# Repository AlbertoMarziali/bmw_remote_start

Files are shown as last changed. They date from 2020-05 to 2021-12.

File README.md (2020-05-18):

# BMW F30 REMOTE START
BMW F30 Remote start project, made with Arduino

# Features
This project allows to do this things:
- If the engine is off, remote start the car with a triple click on the lock button of the OEM keyfob.
- After 15 minutes from remote start, if no one started driving, automatically shut off the car
- If the engine is on, remote stop the car with a triple click on the lock button of the OEM keyfob.
- You have to unlock the car before driving it (why wouldn't you) or it will perform an emergency anti-thief stop

# How it works
The Arduino, thanks to the MCP2515 board, constantly listen to the BMW K-CAN2 bus, looking for a triple lock button click. If found, it starts a 18 seconds long operation, during which it does those steps:
1. Turns on the in-car keyfob
2. Unlocks the car
3. Locks the car 
4. Virtually presses the start button, turning on the ignition
5. Waits some seconds, to let the engine be ready to start.
6. Virtually presses the brake and the start button, turning on the engine
7. Turns off the in-car key.

# Security issues
**What happens if a thief enter the car (by smashing the window) and tries to steal it?**

If someone tries to engage a gear with the car remote started, without unlocking it with a keyfob first, the car automatically shuts off.

**The spare key is always in the car. Wouldn't this be enough to allow a thief to turn on the engine?**

Yes, but actually no. The Arduino turns on the keyfob only when it needs it to remote start. Normally the key isn't powered so the car doesn't see it and can't be turned on!

**Why do the Arduino open and close the car before starting the engine?**

The lock and unlock thing is needed to be able to turn on the ignition. This is because of the BMW security protocol, which disables the possibility of turning on the car if the car wasn't opened before. This is not a security issues though, because this process happens in 2 seconds and the car remains open for just 1 second.

# Required things
Here's a list of things you need for this project:
- Arduino Nano
- LM2596S voltage regulator board, with the output regulated to 5V
- MCP2515 Canbus board (Niren)
- 6x Relay Board with 5V relays
- 2x 560Ω (to replicate the start button internal 560Ω resistor) 
- 1x 1100Ω (to replicate the 12mA current outputted by the hall sensor inside the brake light switch)
- The spare keyfob

You can get those resistance values by putting more resistors in series and sum the resistance value.
For example:
- to get a 550Ω resistance, you can put 220Ω and 330Ω resistors in series! 
- to get a 1100Ω resistance, you can put 1kΩ and 100Ω resistors in series!

# Wiring
You have to do the wiring for:
- KCan2 bus
- 12V and GND
- Brake light switch
- Start button switches
- Keyfob battery
- Keyfob lock switch
- Keyfob unlock switch

## Car Wiring

**KCAN2**

Attention: the OBD2 port doesn't have KCAN2. You can't use it. You have to take KCAN2 from the FEM
- KCAN2_H: FEM A173\*8B, pin 50
- KCAN2_L: FEM A173\*8B, pin 49

**12V and GND**

Attention: you can't use the 12V plug as power source, you need an always-powered 12V source. You can find it at the FEM.
- 12V: FEM A173\*3B, pin 33
- GND: FEM A173\*3B, pin 6

**Brake Light Switch and Start-Stop Button**

Here you can see how to wire break light switch and start/stop button:
- The start-stop button wiring is right behind the switch button, just pull it out.
- The break light switch wiring is above the brake pedal.

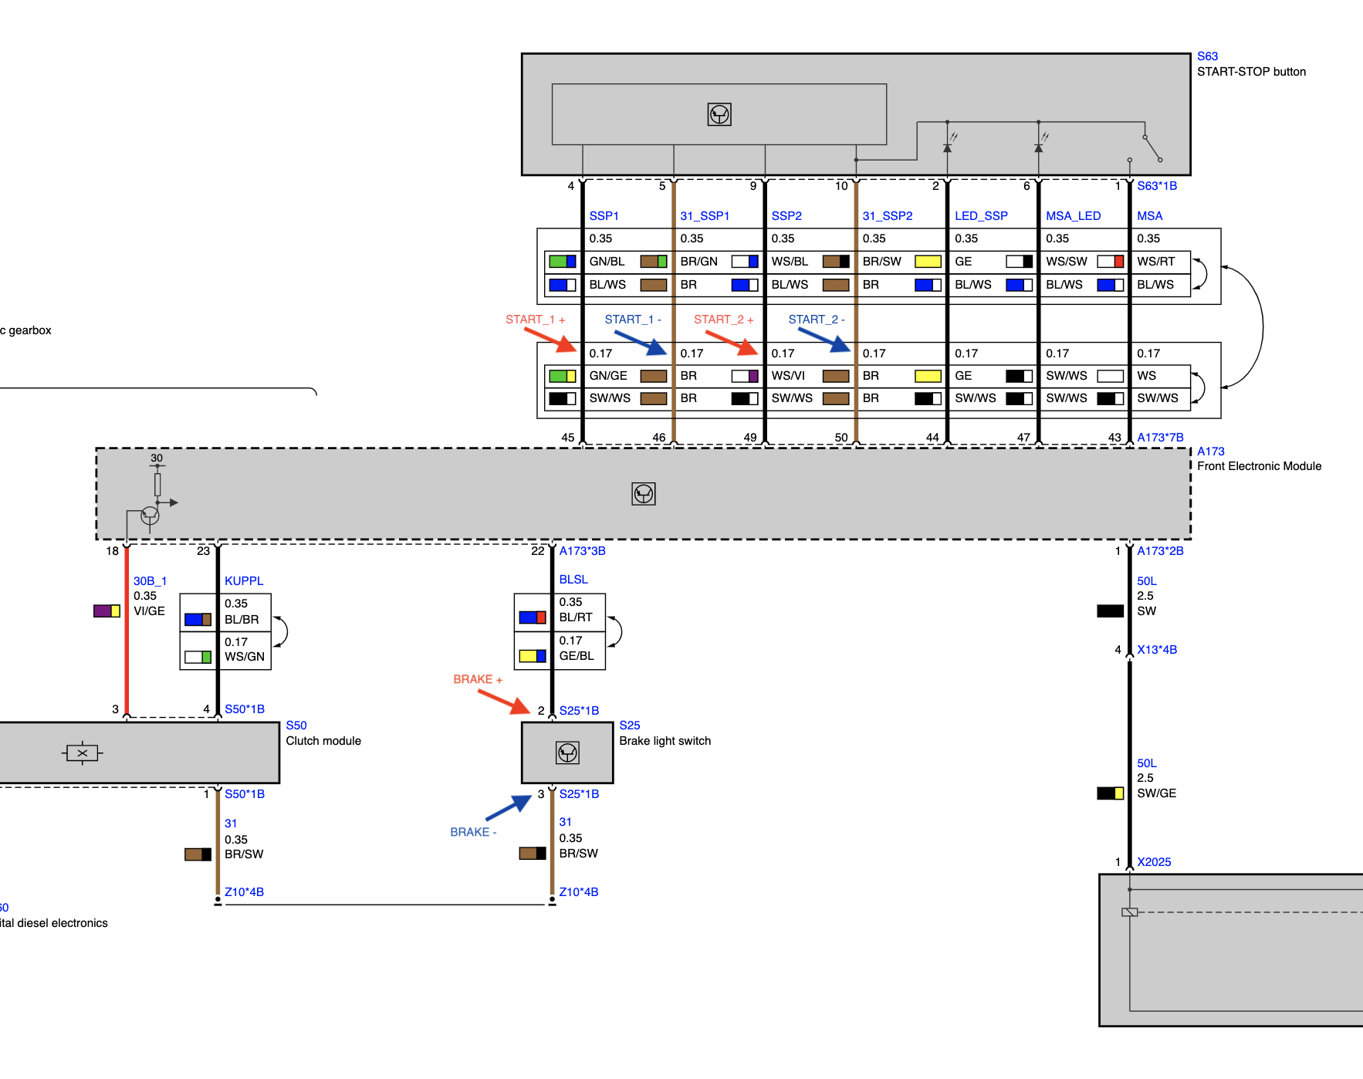
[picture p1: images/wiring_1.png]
CAR Wiring


## KeyFob Wiring

**KeyFob Power**

You have to interrupt the battery positive connection, split it in 2 wires and feed them inside the relay:

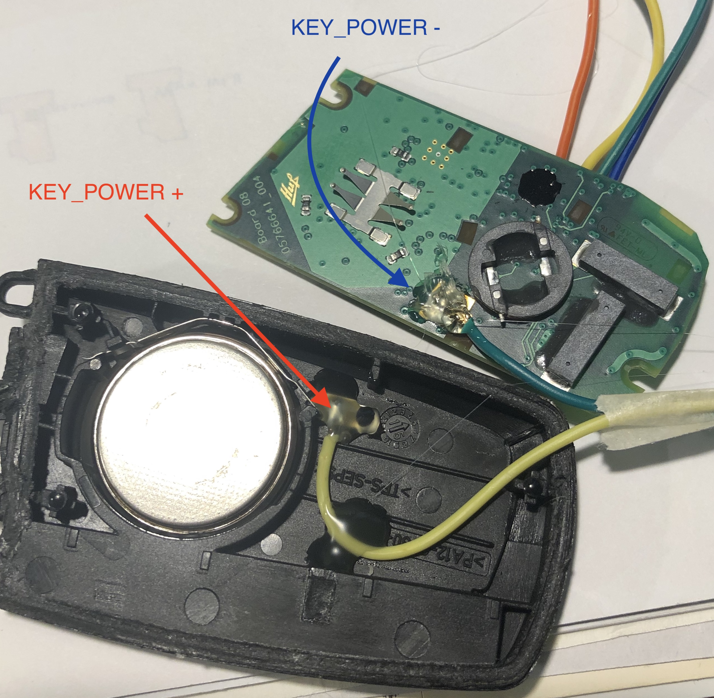
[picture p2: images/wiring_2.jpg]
KEY_POWER wiring


**KeyFob Lock and Unlock buttons**

You have to simulate the press of the switch using the relay. To do that, just hook to the key switches like that:

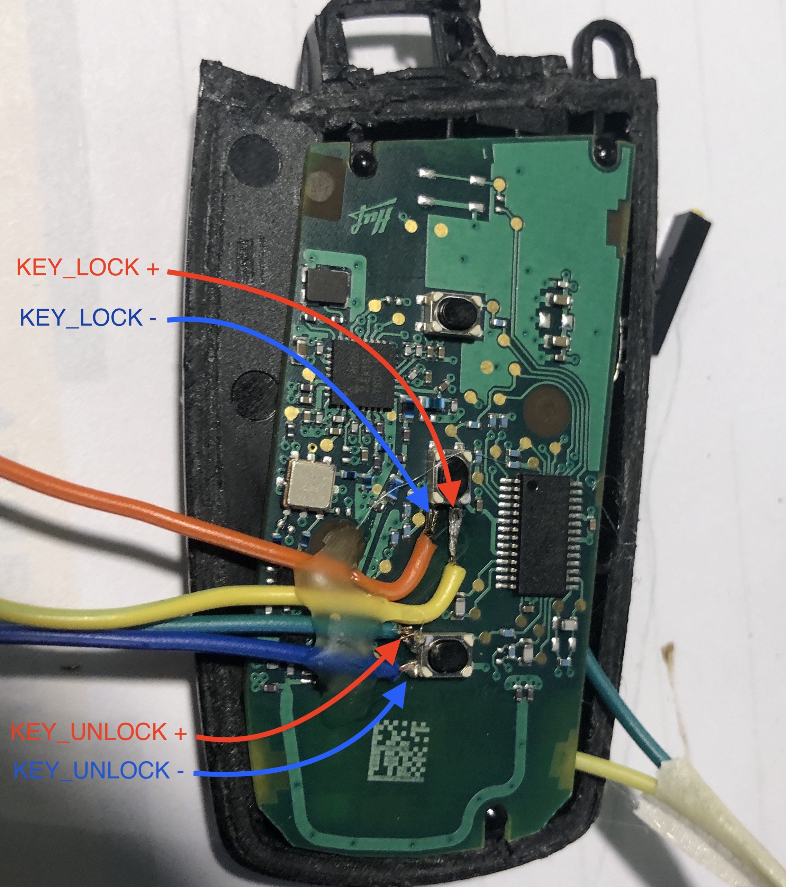
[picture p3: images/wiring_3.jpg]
KEY_LOCK/UNLOCK wiring


## Arduino wiring

**Schematic**

You can follow this schematic to build everything.
Note: this schematic shows a 8x relay board, but you can use a 6x one

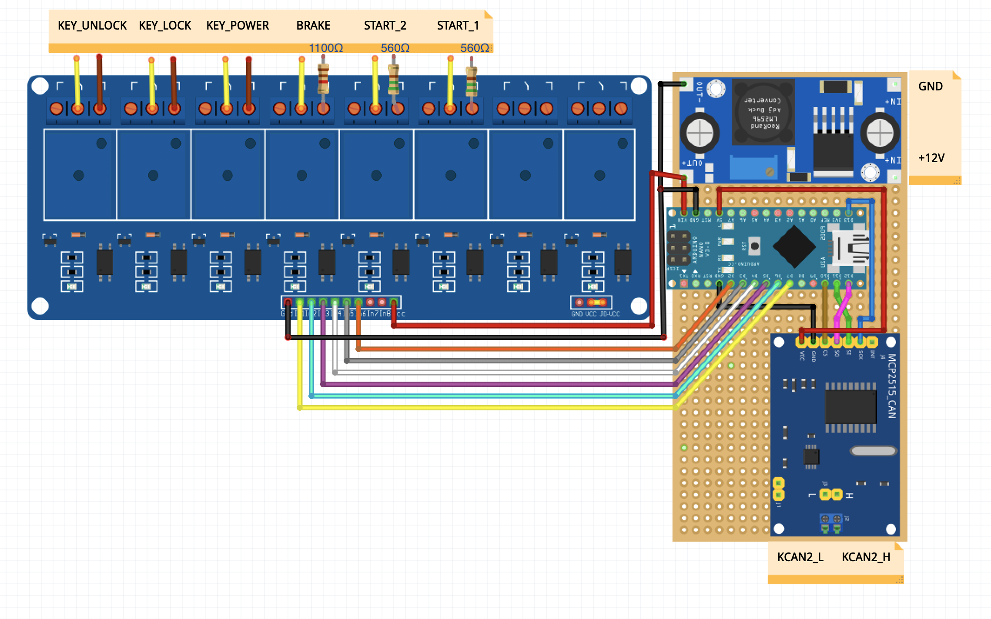
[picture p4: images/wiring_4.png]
arduino wiring


**Final look**

This is the final look, with the spare key wired. You have to hide it somewhere inside the car.
(it's ugly, I know. You can make it definitely better)
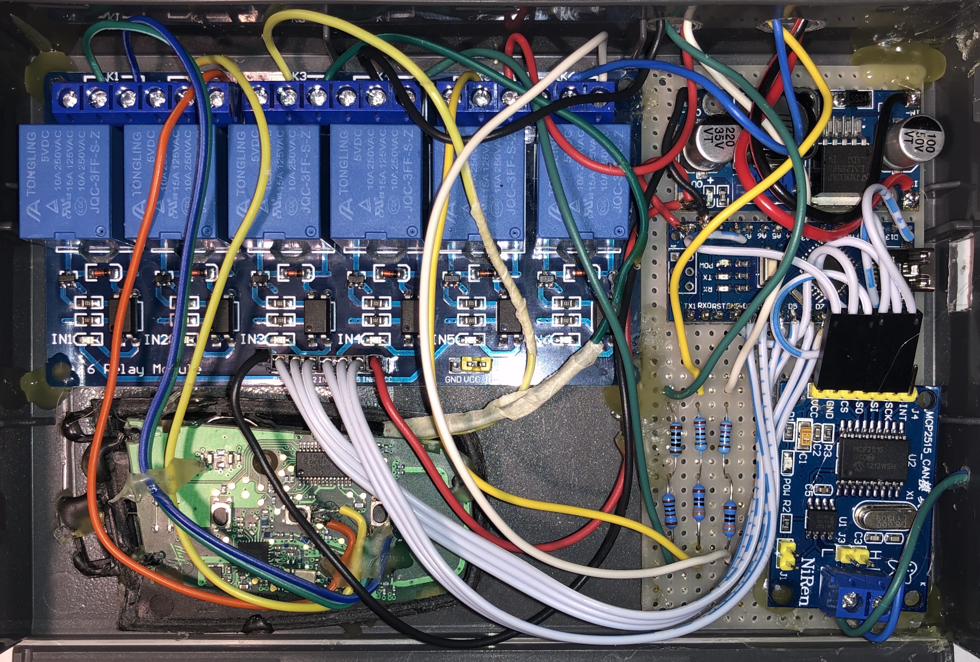
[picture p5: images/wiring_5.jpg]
arduino_final wiring


# Credits
autowp for [arduino-mcp2515 library](https://github.com/autowp/arduino-mcp2515)

# Donate
If you like my work, feel free to [donate me](https://www.paypal.com/cgi-bin/webscr?cmd=_s-xclick&hosted_button_id=96KHFR9W2UR7E&source=url)! I would highly appreciate it!

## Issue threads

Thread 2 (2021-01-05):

Ii

WhiteBimmer1337, 2021-01-05:
Hello, first of all: amazing project.
I‘d really like to add this feature to my car.
The problem is I‘m running a manual transmission. Is it possible for you to add another rev. of the code, which presses the clutch virtually instead of the brake?

kind regards, WhiteBimmer

AlbertoMarziali, 2021-01-05:
Hi! Thanks for the interest. Unfortunately, there's no way to do this in Manual Transmission. At least, not a safe way. (what if you forgot the car in gear?)

WhiteBimmer1337, 2021-01-05:
Hey, thanks for your quick response. Im well aware of the risks involved. I stumbled upon your project, because I‘ve been looking for a cheap way to start the Car couple minutes before leaving in the morning. After a little bit of thinking, i figured I could use your project, measure the resistance of the clutch paddle sensor, apply the correct resistors and just wire it to where the Brake Sensor is pinned on your pcb. Is that correct?

Best regards

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

hardastyle, 2022-01-26:
In my program I tap into the ground connection of the E-break to ensure the car is not going anywhere. You could do the same with the gear. Tap into it to ensure it's in neutral.

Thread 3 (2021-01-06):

Finding CAN codes

sam632, 2021-01-06:
Hi, I really like this project. How did you find the CAN codes? I plan to use a similar setup but read the codes of button presses on the M1 and M2 steering wheel buttons (since they have no use in my car) and then control external devices such as an LED strip or an exhaust valve using a relay.

Also, are the airbags on KCAN2 in a BMW? Is there a chance the wrong code or something could set them off or stop them from working?

I have a 2014 M135i (F21) but I imagine it is similar to the F30.

Thanks
Sam

hardastyle, 2022-01-26:
There are a couple of programs online to find CAN codes with arduino boards (and their respective .ino source codes).
Then it's just finding it by trial and error while filtering out the noise.
This is one example, but there are some better programs out there.
https://www.instructables.com/Hack-your-vehicle-CAN-BUS-with-Arduino-and-Seeed-C/

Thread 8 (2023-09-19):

Start and Stop with input pin

StarmanBL, 2023-09-19:
Hello,
can someone help me?
I installed everything, I used the "manual" option. (since I drive stick) I had to redo a few steps because it didn't work at first, clutch settings was wrong.
Now everything is workong fine, I even added the shutdown option to press Start Stop twice and turn off the ignition completely.Now I need an option that I can't get at all.  I want to achieve that instead of the original key and by pressing the lock 3 times, I activate the sketch with the input on pin 8, i.e. to start the vehicle on pin 8 (ground switch LOW) and to turn off the vehicle on pin 9 (ground switch LOW) I want to use my device for satellite  tracking that I have in the vehicle and to activate the vehicle with an SMS message.  That part is fine, I can activate output on my device to send ground with sms message...Just can't seem to get the code to work.
Can someone help with adding that option to sketch?

Thank you in advance

StarmanBL, 2023-09-20:
I add this function and it's working, now I can start and stop car with SMS comand :) if someone need this complete code for BMW F30 manual gearbox, let me know

Joergejuan25, 2024-04-16:
> Agregué esta función y está funcionando, ahora puedo arrancar y detener el auto con un comando SMS :) si alguien necesita este código completo para la caja de cambios manual BMW F30, hágamelo saber.

Hello, I am developing this project for f30 manual box.
I have 2 questions.
The code is valid for manual boxes, my other question;  Is it necessary for the remote control battery to be installed?
can share for code  manual box.??  I am new to Arduino.
Thanks in advance.

Joergejuan25, 2024-04-16:
> I add this function and it's working, now I can start and stop car with SMS comand :) if someone need this complete code for BMW F30 manual gearbox, let me know

Hello, I am developing this project for f30 manual box.
I have 2 questions.
The code is valid for manual boxes, my other question; Is it necessary for the remote control battery key to be installed?
I would be very grateful if you could share the code for manual transmission. F30.??
I am new to Arduino.
Thanks in advance.

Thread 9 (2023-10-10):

Adding wifi MQTT support

Taz-assistant, 2023-10-10:
Nice job with this turning Keyfob to remote starter.
But is it possible to keep all this AND adding support for MQTT via wifi? In my case the Arduino 33 IoT.

That way it will be possible to program timer etc via Home Assistant or similar

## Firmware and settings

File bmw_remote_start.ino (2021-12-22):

#include <can.h>
#include <mcp2515.h>
#include <SPI.h>

//relays use inverted logic
enum RELAY_STATUS {
    RELAY_HIGH = 0,
    RELAY_LOW = 1
};

//define pinout of transistors
enum RELAYS {
  RELAY_START_1 = 2,  
  RELAY_START_2 = 3,  
  RELAY_BRAKE = 4,
  RELAY_KEY_POWER = 5,
  RELAY_KEY_LOCK = 6,
  RELAY_KEY_UNLOCK = 7
};


//booleans keep track of statuses read from canbus
bool status_engine_running = false;
bool status_lock_button = false;
bool status_brake_light = false;

//engine actions data
bool engine_start = false;
bool engine_stop = false;
unsigned long engine_do_start_time = 0;
unsigned long engine_do_stop_time = 0;

//remote start data
bool remote_started = false;
unsigned long remote_start_time = 0; 

//timing data
int lock_in_a_row = 0;
bool wait_for_lock_release = false;
unsigned long last_lock_detected_time = 0;
unsigned long cur_lock_detected_time = 0;

//can library data
struct can_frame canMsg;
MCP2515 mcp2515(10);


/* CAN CODES
 * BREAK LIGHT
 * 0x21A : data: first bit of Byte[0] is 1 -> break light is on
 * 
 * KEYFOB 
 * 0x23A : data: xx F3 04 3F ->  lock button pressed
 * 0x23A : data: xx F3 01 3F ->  unlock button pressed
 * 0x23A : data: xx F3 00 3F ->  key button released
 * 
 * ENGINE STATUS
 * 0x0A5 : data: Byte[5] = 0x00 and Byte[5] = 0x00 -> if engine is NOT running
 */


void can_updateStatus()
{
  if (mcp2515.readMessage(&canMsg) == MCP2515::ERROR_OK) {
   /* Serial.print(canMsg.can_id, HEX); // print ID
    Serial.print(" "); 
    Serial.print(canMsg.can_dlc, HEX); // print DLC
    Serial.print(" ");
    
    for (int i = 0; i < canMsg.can_dlc; i++)  {  // print the data
      Serial.print(canMsg.data[i], HEX);
      Serial.print(" ");
    }

    Serial.println(); 
  */
    //doing the check!
    if(canMsg.can_id == 0x21A)       //can id for brake light
    {
      if (canMsg.data[0] & 0x80)     //first bit of first byte is 1
      {
        Serial.println("Brake on"); 
        status_brake_light = true;
      }
      else
      {
        Serial.println("Brake off"); 
        status_brake_light = false;
      }
    }
    else if(canMsg.can_id == 0x23A)  //can id for keyfob
    {
      if(   (canMsg.data[1] == 0xF3)
         && (canMsg.data[2] == 0x04)
         && (canMsg.data[3] == 0x3F)) //data = 11 F3 04 3F ->  lock button pressed
       {
         Serial.println("Lock button pressed"); 
         status_lock_button = true;
       }
      else if((canMsg.data[1] == 0xF3)
         && (canMsg.data[2] == 0x01)
         && (canMsg.data[3] == 0x3F)) //data = 11 F3 01 3F ->  unlock button pressed
       {
         Serial.println("Unlock button pressed, out of remote start scope"); 
         remote_started = false;
       }
      else if((canMsg.data[1] == 0xF3)
         && (canMsg.data[2] == 0x00)
         && (canMsg.data[3] == 0x3F)) //data = 11 F3 00 3F ->  key button released
       {
         Serial.println("Key button released"); 
         status_lock_button = false;
       }
      
    }
    else if(canMsg.can_id == 0x0A5)  //can id for engine status
    {
      //engine running status
      if((canMsg.data[5] == 0x00 &&
          canMsg.data[6] == 0x00)) //data: Byte[5] = 0x00 and Byte[5] = 0x00 -> if engine is NOT running
       {
         //Serial.println("Engine is NOT running"); 
         status_engine_running = false;

         
         //give one second to update canbus
         if(remote_started && (millis() - remote_start_time > 1000))
            remote_started = false;
       }
       else
       {
         Serial.println("Engine is running"); 
         status_engine_running = true;
       }
    }
  }
}

void can_setup()
{
  //reset mcp2515 and set can at 500KBPS and MCP to 8MHz quartz
  mcp2515.reset();
  mcp2515.setBitrate(CAN_500KBPS, MCP_8MHZ);

  //init the mask
  mcp2515.setFilterMask(MCP2515::MASK0, 0, 0x3ff);
  mcp2515.setFilterMask(MCP2515::MASK1, 0, 0x3ff);

  //init the filters
  mcp2515.setFilter(MCP2515::RXF0, 0, 0x21A); //break light
  mcp2515.setFilter(MCP2515::RXF1, 0, 0x23A); //keyfob
  mcp2515.setFilter(MCP2515::RXF2, 0, 0x0A5); //rpm

  //start the sniffing
  mcp2515.setNormalMode();
  
}


/* ENGINE START:
 * 1) Turn on the in-car key (100 ms)
 * 2) Press lock button (300 ms)
 * 3) Release lock button and wait (400 ms)
 * 4) Start holding the brake and wait (5 sec)
 * 5) Press the start button (2 sec)
 * 6) Release the start button and wait (1 sec)
 * 7) Release the brake and wait (1 sec)
 * 8) Turn off the in-car key (1 sec)
 */

void engine_do_start()
{
  if(engine_do_start_time == 0)
  {
   engine_do_start_time = millis();
   Serial.println("*** Engine starting ***");
  }
  
  //divided in phases:
  //KEY_POWER_ON - 100 ms
  if(millis() - engine_do_start_time < 100)
  {
    digitalWrite(RELAY_KEY_POWER, RELAY_HIGH);
    Serial.println("1) Turn on the in-car key (100 ms)");
  }
  //KEY_LOCK - 300 ms
  else if(millis() - engine_do_start_time < 400)
  {
    digitalWrite(RELAY_KEY_LOCK, RELAY_HIGH);
    Serial.println("2) Press lock button (300 ms)");
  }
  //KEY_LOCK_RELEASE - 400 ms
  else if(millis() - engine_do_start_time < 800)
  {
    digitalWrite(RELAY_KEY_LOCK, RELAY_LOW);
    Serial.println("3) Release lock button and wait (400 ms)");
  }
  //BRAKE - 100 ms
  else if(millis() - engine_do_start_time < 2800)
  {
    digitalWrite(RELAY_BRAKE, RELAY_HIGH);
    Serial.println("8) Start holding the brake and wait (2000 ms)");
  }
  //START - 1500 ms
  else if(millis() - engine_do_start_time < 4300)
  {
    digitalWrite(RELAY_START_1, RELAY_HIGH);
    digitalWrite(RELAY_START_2, RELAY_HIGH);
    Serial.println("9) Press the start button (1500 ms)");
  }
  //START_RELEASE - 100 ms
  else if(millis() - engine_do_start_time < 4400)
  {
    digitalWrite(RELAY_START_1, RELAY_LOW);
    digitalWrite(RELAY_START_2, RELAY_LOW);
    Serial.println("10) Release the start button and wait (100 ms)");
  }
  //BRAKE_RELEASE - 200 ms
  else if(millis() - engine_do_start_time < 4600)
  {
    digitalWrite(RELAY_BRAKE, RELAY_LOW);
    Serial.println("11) Release the brake and wait (200 ms)");
  }
  //KEY_POWER_RELEASE - 100 ms
  else if(millis() - engine_do_start_time < 4700)
  {
    digitalWrite(RELAY_KEY_POWER, RELAY_LOW);
    Serial.println("12) Turn off the in-car key (100 ms)");
  }
  //ENGINE STARTED
  else
  {
    remote_started = true;
    remote_start_time = millis();
    engine_do_start_time = 0;
    engine_start = false;

    Serial.println("*** Engine started ***");
  }
}
  


/* ENGINE STOP:
 * 1) Press start button (700 ms)
 * 2) Release the start button and wait (100 ms)
 */

void engine_do_stop()
{
  if(engine_do_stop_time == 0)
  {
    engine_do_stop_time = millis();
    Serial.println("*** Engine stopping ***");
  }

  //START - 700 ms
  if(millis() - engine_do_stop_time < 700)
  {
    digitalWrite(RELAY_START_1, RELAY_HIGH);
    digitalWrite(RELAY_START_2, RELAY_HIGH);
    Serial.println("1) Press start button (700 ms)");
  }
  //START_RELEASE - 1 sec
  else if(millis() - engine_do_stop_time < 800)
  {
    digitalWrite(RELAY_START_1, RELAY_LOW);
    digitalWrite(RELAY_START_2, RELAY_LOW);
    Serial.println("2) Release the start button (100 ms)");
  }
  //ENGINE STOPPED
  else
  {
    engine_do_stop_time = 0;
    engine_stop = false;
    remote_started = false;
    Serial.println("*** Engine stopped ***");
  }
}



void setup() {  
  Serial.begin(9600);
  Serial.println("[ BMW REMOTE START v1 ]");
  
  pinMode(RELAY_START_1, OUTPUT);       
  pinMode(RELAY_START_2, OUTPUT); 
  pinMode(RELAY_BRAKE, OUTPUT);
  pinMode(RELAY_KEY_POWER, OUTPUT);
  pinMode(RELAY_KEY_LOCK, OUTPUT);
  pinMode(RELAY_KEY_UNLOCK, OUTPUT);

  digitalWrite(RELAY_START_1, RELAY_LOW);
  digitalWrite(RELAY_START_2, RELAY_LOW);
  digitalWrite(RELAY_BRAKE, RELAY_LOW);
  digitalWrite(RELAY_KEY_POWER, RELAY_LOW);
  digitalWrite(RELAY_KEY_LOCK, RELAY_LOW);
  digitalWrite(RELAY_KEY_UNLOCK, RELAY_LOW);

  //setup MCP2515
  can_setup();
}  
 
void loop() {  

    //update status
    can_updateStatus();


    //reset the timer if timeout from previous lock
     if(millis() - last_lock_detected_time > 1500) 
      lock_in_a_row = 0;

    //working on the triple lock click thing
    if(!wait_for_lock_release && status_lock_button) //lock clicked for first time
    {
      cur_lock_detected_time = millis(); //I save the lock button pressed
      wait_for_lock_release = true;
    }
    else if(wait_for_lock_release && !status_lock_button) //lock released for first time
    {
      wait_for_lock_release = false;
      if(millis() - cur_lock_detected_time < 1000) //if release happened in a short time (not an hold), count it as click in a row
      {
        lock_in_a_row++;
        last_lock_detected_time = millis(); //store the lock click detected time

        Serial.print("lock detected: ");
        Serial.print(lock_in_a_row, DEC);
        Serial.print("/3\n");
      }
    }

    //at third lock detected
    if(lock_in_a_row == 3) //if we reached the number we wanted
    {
      lock_in_a_row = 0;
      last_lock_detected_time = 0;

      //use triple click action only if it's not already turning on or off
      if(!engine_start && !engine_stop)
        if(!remote_started && !status_engine_running) //if not in remote start phase and the engine is not already running
        {
          //init preheating
          engine_start = true;
        }
        else
        {
          //engine stop
          engine_stop = true;
        }
    }
    
    /* --- EMERGENCY STOP ---
    * if you enter the remote started car (1 sec bonus for canbus to update), 
    * without unlocking the car (eg. a thief trying to steal the car)
    * and press the brake, exit remote start scope
    */
    if(remote_started && (millis() - remote_start_time > 2000) && status_brake_light)
    {
      //out of remote start scope
      Serial.println("** EMERGENCY ANTI-THIEF STOP **");
      engine_stop = true;
      remote_started = false;
    }

    //remote start timeout
    //car in remote start shutsoff after 15 minutes
    if(remote_started && (millis() - remote_start_time > (unsigned long) 1000 * 60 * 15))
    {
      //engine stop
      Serial.println("** TIMEOUT STOP **");
      engine_stop = true;
      remote_started = false;
    }

    //Now that everything is decided, do the things it has to do

    //engine start
    if(engine_start)
      engine_do_start();

    //engine preheating
    if(engine_stop)
      engine_do_stop();
    
    
    
}

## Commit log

2020-05-05 added labels
    [bmw_remote_start.fzz]
2020-05-05 added more debug
    [bmw_remote_start.fzz]
2020-05-06 completely rewritten script!
    [bmw_remote_start.fzz]
2020-05-06 added car lock and unlock with keyfob
    [bmw_remote_start.fzz]
2020-05-07 close the car before preheating
    also added another transistor
    [bmw_remote_start.fzz]
2020-05-08 keep track of remote start time
2020-05-10 4n35 replaced with nmos for key pow
    [bmw_remote_start.fzz]
2020-05-10 code reworked, 4n35 replaced with relays
    [bmw_remote_start.fzz]
2020-05-10 fixed vcc and gnd for relay board
    [bmw_remote_start.fzz]
2020-05-11 updated .ino to use relay
2020-05-11 updated schematics
    [bmw_remote_start.fzz]
2020-05-11 now using relay logic
    [bmw_remote_start.fzz]
2020-05-14 added images, reworked fzz
    [bmw_remote_start.fzz]
2020-05-15 added 3 resistors, now it's working!
    [bmw_remote_start.fzz]
2020-05-15 updated wiring with resistors
2020-05-15 updated schematic
2020-05-16 added voltage info in readme
    [bmw_remote_start.fzz]
2020-10-07 fix for petrol engine
    [bmw_remote_start.ino]
